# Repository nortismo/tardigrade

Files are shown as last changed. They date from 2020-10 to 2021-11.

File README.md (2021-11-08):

# Tardigrade

Tardigrade is an open hardware low-power board featuring NXP's LPC55S16 MCU, Semtech's SX1262 LoRa transceiver, u-blox's MAX-8Q GNSS module and Microchip's ATECC608A secure-element. It can be used as it is already or modified to your own needs. 

## Hardware

Schema and layout was created using [KiCad](https://kicad.org/).

## Software

There's a port of the official LoRaWAN stack implementation "LoRaMac-node" from Semtech for the Tardigrade board. The software is managed in a separate [GitHub repository](https://github.com/nortismo/LoRaMac-node).

## License

This hardware is licensed under the [TAPR Open Hardware License](https://tapr.org/the-tapr-open-hardware-license/). Please see the [LICENSE.txt](LICENSE.txt) file.

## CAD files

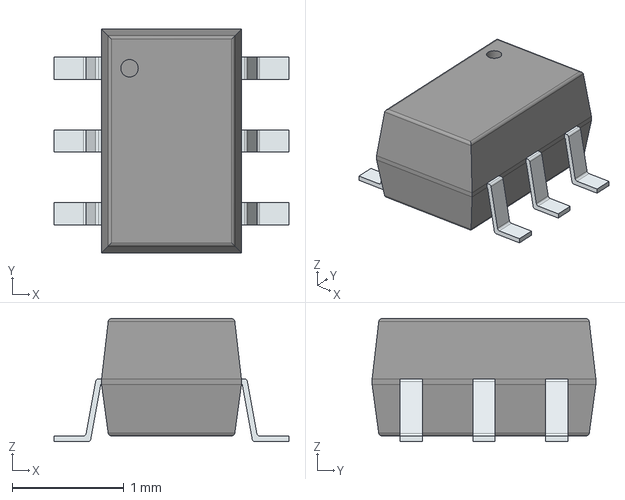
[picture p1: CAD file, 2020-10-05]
3d-models/MMDT2907A-7-F.stp
2.10 x 2.00 x 1.10 mm
PinsArrayLR

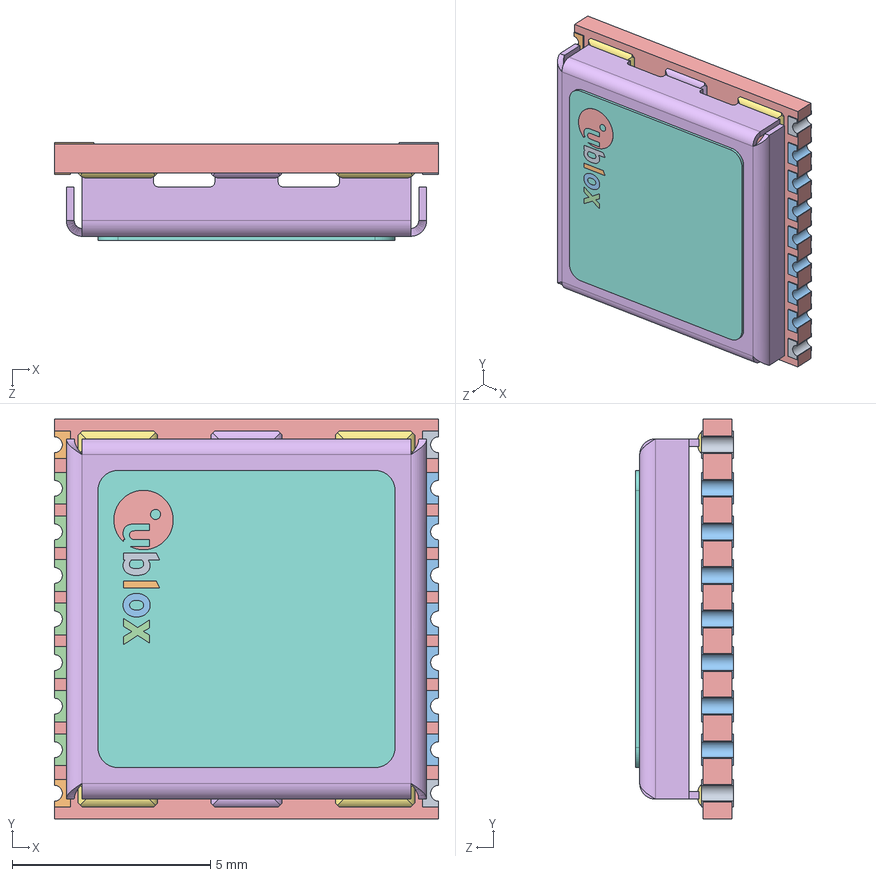
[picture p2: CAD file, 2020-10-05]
3d-models/MAX (STEP-AP203).STEP
9.70 x 10.1 x 2.47 mm
MAX_PCB
u-blox_MAX_label_Default
Shield

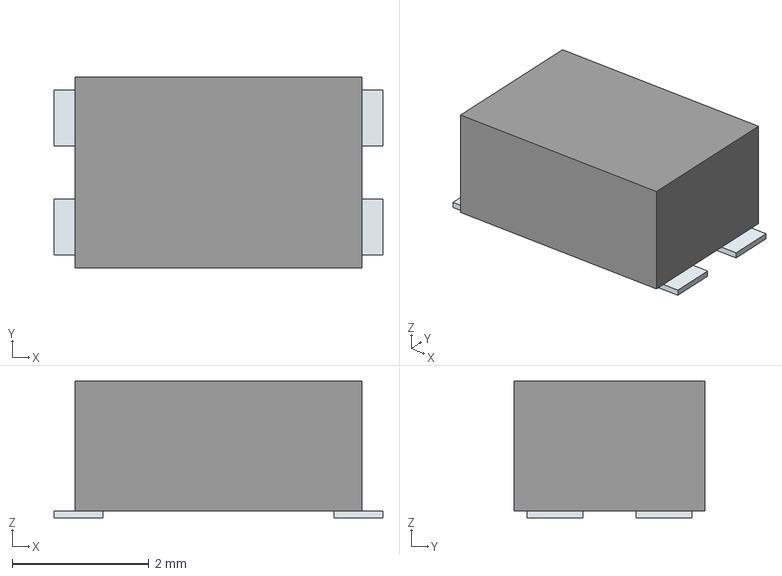
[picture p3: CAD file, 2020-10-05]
3d-models/KMR221NGLFS.stp
4.82 x 2.80 x 2.00 mm
Pins

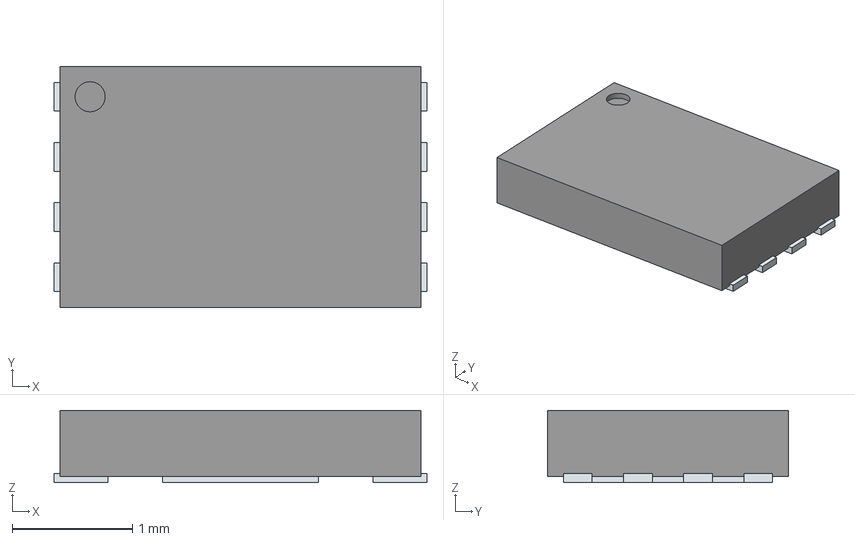
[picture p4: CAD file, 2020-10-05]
3d-models/ATECC608A-TNGLORAU-B.stp
3.10 x 2.00 x 0.6 mm
ThermalPin
PinsArrayLR

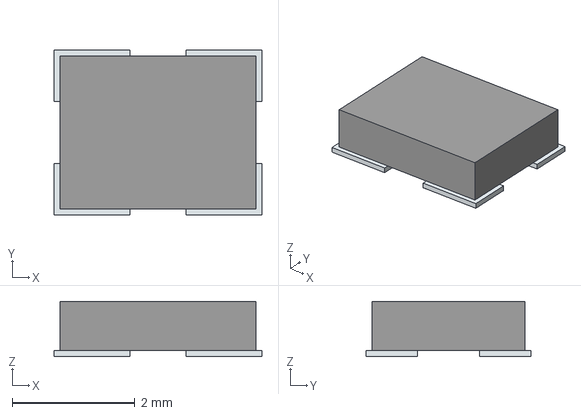
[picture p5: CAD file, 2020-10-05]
3d-models/CX3225SA40000D0PTWCC.stp
3.39 x 2.69 x 0.9 mm
Pins

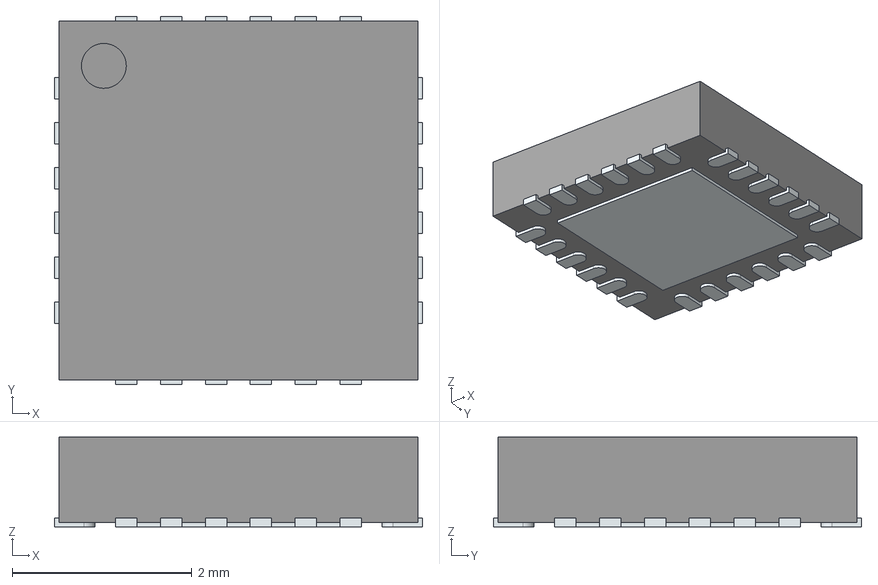
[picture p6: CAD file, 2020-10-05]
3d-models/SX1262IMLTRT.stp
4.10 x 4.10 x 1.00 mm
ThermalPin
PinsArrayLR
PinsArrayTB

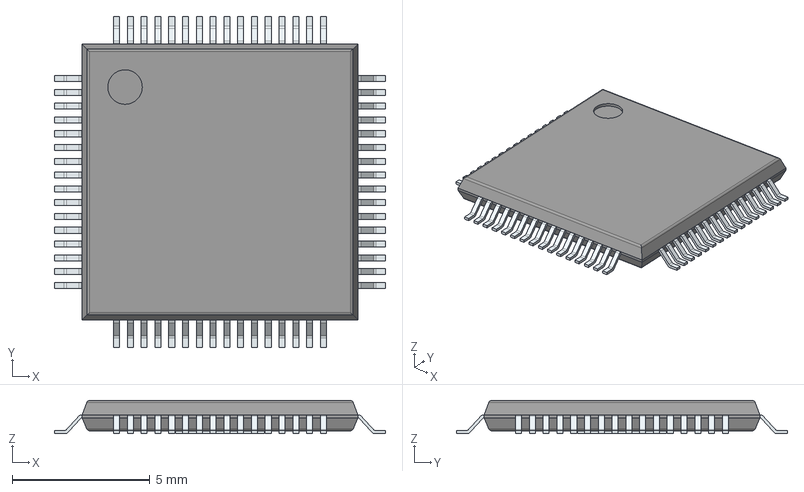
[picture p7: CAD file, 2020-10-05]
3d-models/LPC55S16JBD64E.stp
12.0 x 12.0 x 1.20 mm
PinsArrayLR
PinsArrayTB
ThermalPad

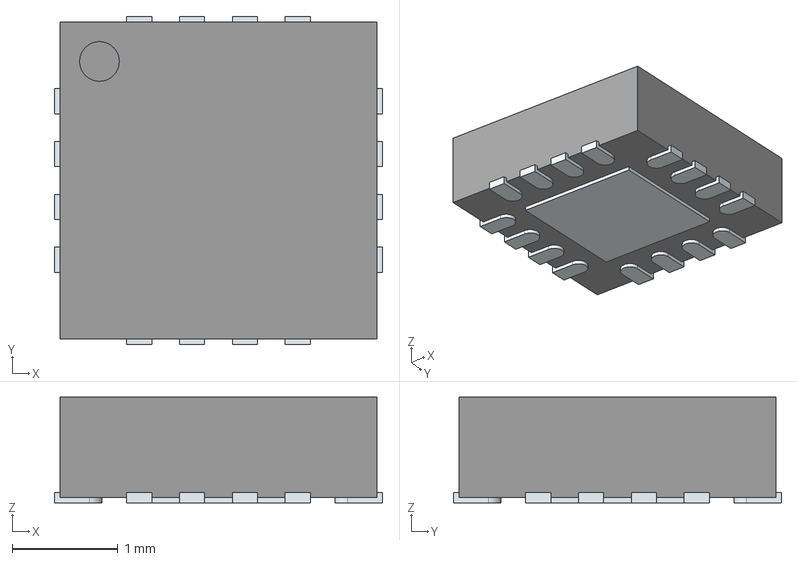
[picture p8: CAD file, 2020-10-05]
3d-models/BQ25504RGTT.stp
3.10 x 3.10 x 1.00 mm
ThermalPin
PinsArrayLR
PinsArrayTB

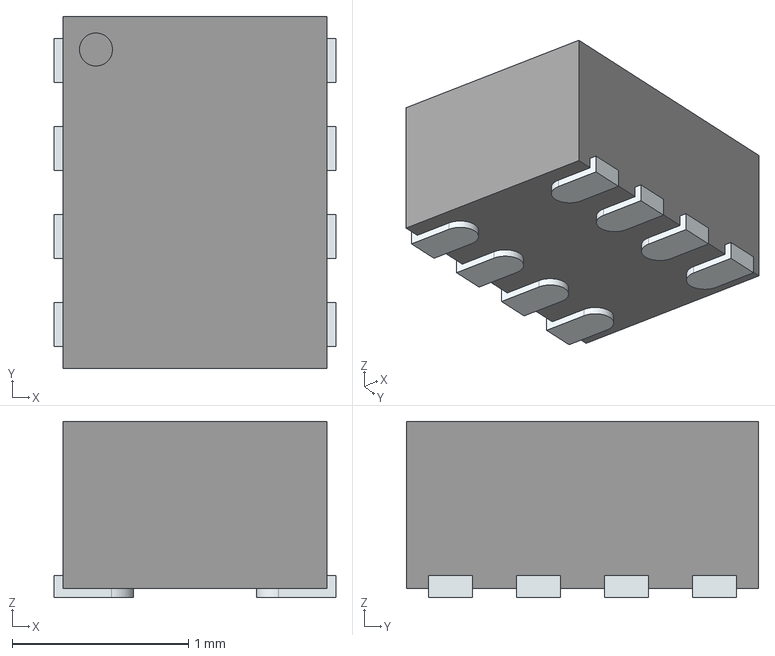
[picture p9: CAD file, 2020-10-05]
3d-models/TPS62840DLCR.stp
1.60 x 2.00 x 1.00 mm
PinsArrayLR

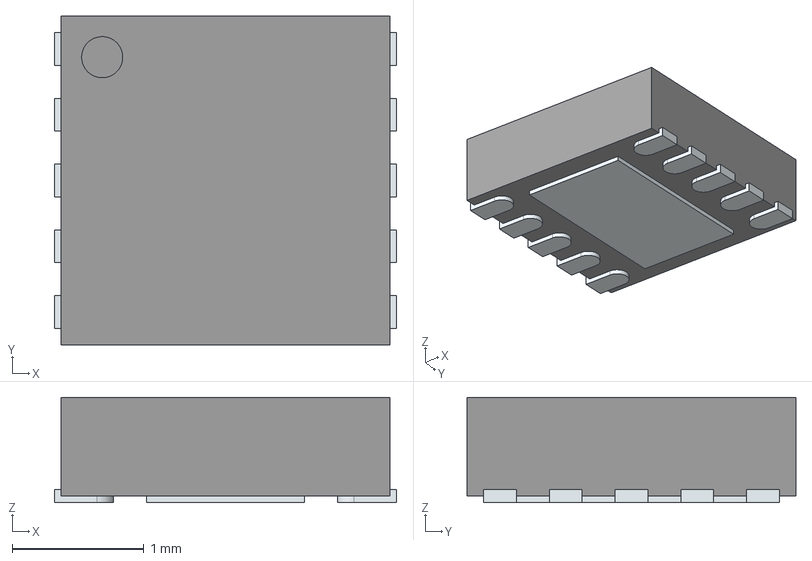
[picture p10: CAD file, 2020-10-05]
3d-models/TPS63031DSKR.stp
2.60 x 2.50 x 0.8 mm
ThermalPin
PinsArrayLR

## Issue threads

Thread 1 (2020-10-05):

L1 and L3 footprints are to small

nortismo, 2020-10-05:
# L1 and L3 footprints are too small

It's hard or nearly impossible to find a suitable L1 and L3 inductance with the desired values. Therefore different footprints for these two components have to be used, e.g. _0603 or_ even _0805_.

nortismo, 2020-11-12:
Footprints changed with commit fdd46cc9a01f37fd9c26f2f6ec00a6c7477109f7

Closed 2020-11-12.

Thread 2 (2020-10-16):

BQ_AVSS doesn't have a connection to GND

nortismo, 2020-10-16:
# BQ_AVSS doesn't have a connection to GND

The analog ground from BQ25504 called _BQ_AVSS_ doesn't have any connection to GND. Instead, it should be connected to GND as close as possible, directly at one point underneath the IC.

nortismo, 2020-11-05:
Fixed issue with commit d6d381544372e4fbed15211944ae5a9a2032be78 and added a connection between BQ_AVSS and GND

Closed 2020-11-05.

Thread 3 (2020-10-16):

BQ25504 doesn't start without solar power input

nortismo, 2020-10-16:
# BQ25504 doesn't start without solar power input

The IC BQ25504 doesn't start as long as there is no power from the solar panel, even if there is a voltage from VIN (battery or USB). Therefore the board only starts if one connects a solar panel or another power source to these pins.

nortismo, 2020-11-05:
Fixed issue with commit d6d381544372e4fbed15211944ae5a9a2032be78: Added a connection from VBUS to the solar panel with a resistor and a diode in between. This allows a small current flowing from VBUS to VIN_DC of the BQ25504 and therefore lets the boost converter start.

Closed 2020-11-05.

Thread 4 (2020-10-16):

Battery required to run the board on USB power

nortismo, 2020-10-16:
# Battery required to run the board on USB power

The Tardigrade can't be powered by USB without having a battery connected. The power ICs require a minimum capacitance which is given with the connected battery.

nortismo, 2020-11-05:
Fixed issue with commit d6d3815: Added a capacitor in front of the LIPO battery connector in order to be able to run the board without the battery.

Closed 2020-11-05.

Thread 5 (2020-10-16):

Missing C at LIPO charger MCP73831T

nortismo, 2020-10-16:
# Missing C at LIPO charger MCP73831T

The input pin VDD of the MCP73831T is missing a decoupling capacitor. To support the input power, a C of 10uF between VDD and GND can be placed as close as possible to the pin.

nortismo, 2020-11-05:
Fixed issue with commit d6d3815: Added the capacitor.

Closed 2020-11-05.

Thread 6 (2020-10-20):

C21 is wrong

nortismo, 2020-10-20:
# C21 is wrong

C21 should be a decoupling C for the input of _VDD_PMU_, but the schema is wrong. It must not be placed serially in line, but has to be connected parallel to Ground. Implementing it like designed in the schema, the MCU won't be powered correctly and the board doesn't work at all.

nortismo, 2020-11-05:
Fixed this issue with commit 966d3598cd48d5903a0eeb48dfa97b62b6b12088 - Schematic was changed accordingly with the proper placement of the capacitors.

Closed 2020-11-05.

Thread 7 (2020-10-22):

Connect RESET of SX1262 and GNSS to RESET button

nortismo, 2020-10-22:
# Connect RESET of SX1262 and GNSS to RESET button

In order to reset the whole board properly, the RESET line of the SX1262 and the GNSS module have to be connected to the RESET button as well. With the current schema, only the MCU is resetting when pressing that button. As a consequence, the initialization of the SX1262 doesn't work properly without a software reset first.

nortismo, 2020-11-05:
This won't be implemented and can be done with software.

Closed 2020-11-05.

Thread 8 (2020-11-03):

High power consumption of the LoRa transceiver resets the board

nortismo, 2020-11-03:
The LoRa transceiver SX1262 demands a lot of power over a short time when sending. This demand causes the voltage to collapse and resets the whole board.

nortismo, 2020-11-06:
This should be solved with commit 08f9730cbffbf505b7fb2e199a95f4603e357f8c: The DCDC converter is now directly connected to the battery and should deliver enough power for the lora transceiver.

Closed 2020-11-06.

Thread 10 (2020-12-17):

Add MOSFET to GNSS module in order to save power

nortismo, 2020-12-17:
Currently, the GNSS module MAX-8Q from u-blox can be put into backup mode to save power. But the module still consumes around 20 uA in this mode, which is quite a lot compared to the rest of the board. In order to bring down this value, one could add a P-Channel Enhancement MOSFET between VCC and the GNSS module. The power source to the GNSS module could then be turned on or off within the software running on the MCU.

One possible MOSFET is the [MIC94053YC6](http://ww1.microchip.com/downloads/en/DeviceDoc/mic94052-53.pdf) from Microchip. It even has an internal pull-up on the gateway pin in order to keep the pin high while there is nothing applied (which would happen when the LPC55S16 goes into deep power down mode). The MOSFET has a Zero Gate Voltage Drain Current of 1 uA. Therefore, we could save around 19 uA with this solution.

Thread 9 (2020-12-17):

SX1262_NSS pin requires pull-up resistor

nortismo, 2020-12-17:
The LPC55S16 leaves all pins floating when going to deep power down mode (lowest low power mode). In order to save power, one usually puts the peripherals like GNSS module or LoRa transceiver into sleep mode as well. But the LoRa transceiver wakes up automatically when the SPI slave select pin is going low. From the datasheet of the SX1261/2 LoRa transceiver:

> Once in SLEEP mode, it is possible to wake the device up from the host processor with a falling edge on the NSS line.

In order to keep the slave select high while the LPC55S16 is in deep power down, a pull-up resistor is required for pin 19 of the LoRa transceiver.

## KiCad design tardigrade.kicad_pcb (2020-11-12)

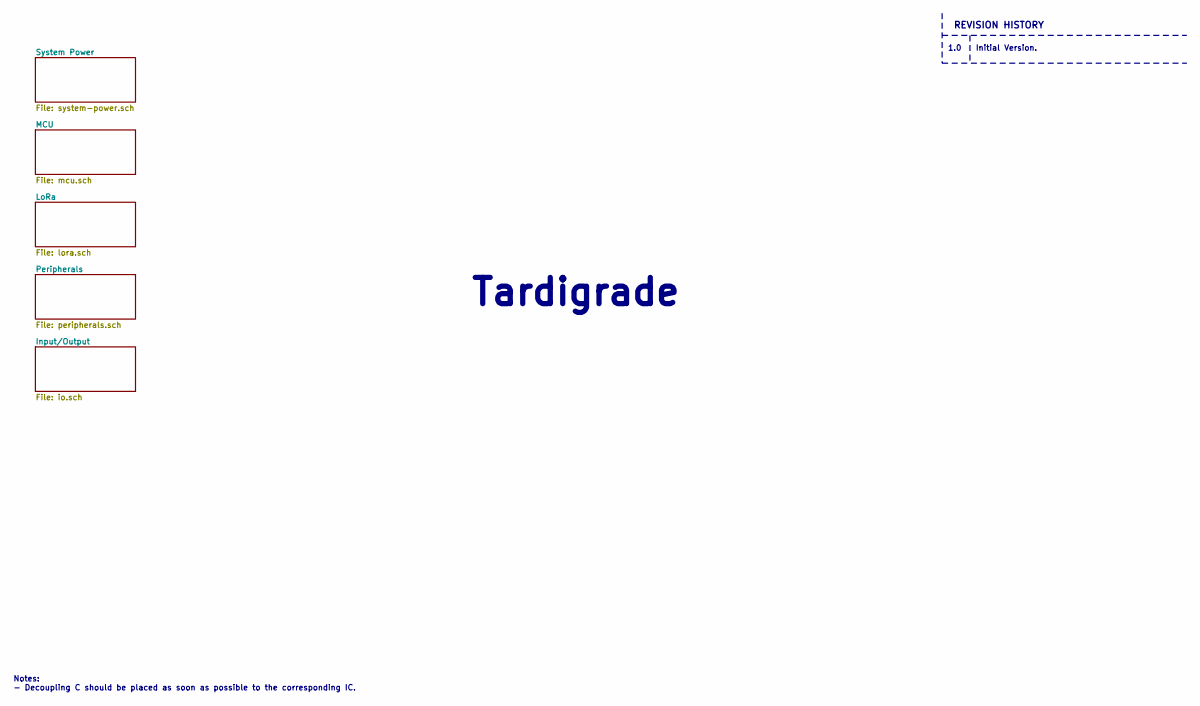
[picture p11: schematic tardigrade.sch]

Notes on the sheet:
REVISION HISTORY
1.0
Initial Version.
Tardigrade
Notes: - Decoupling C should be placed as soon as possible to the corresponding IC.

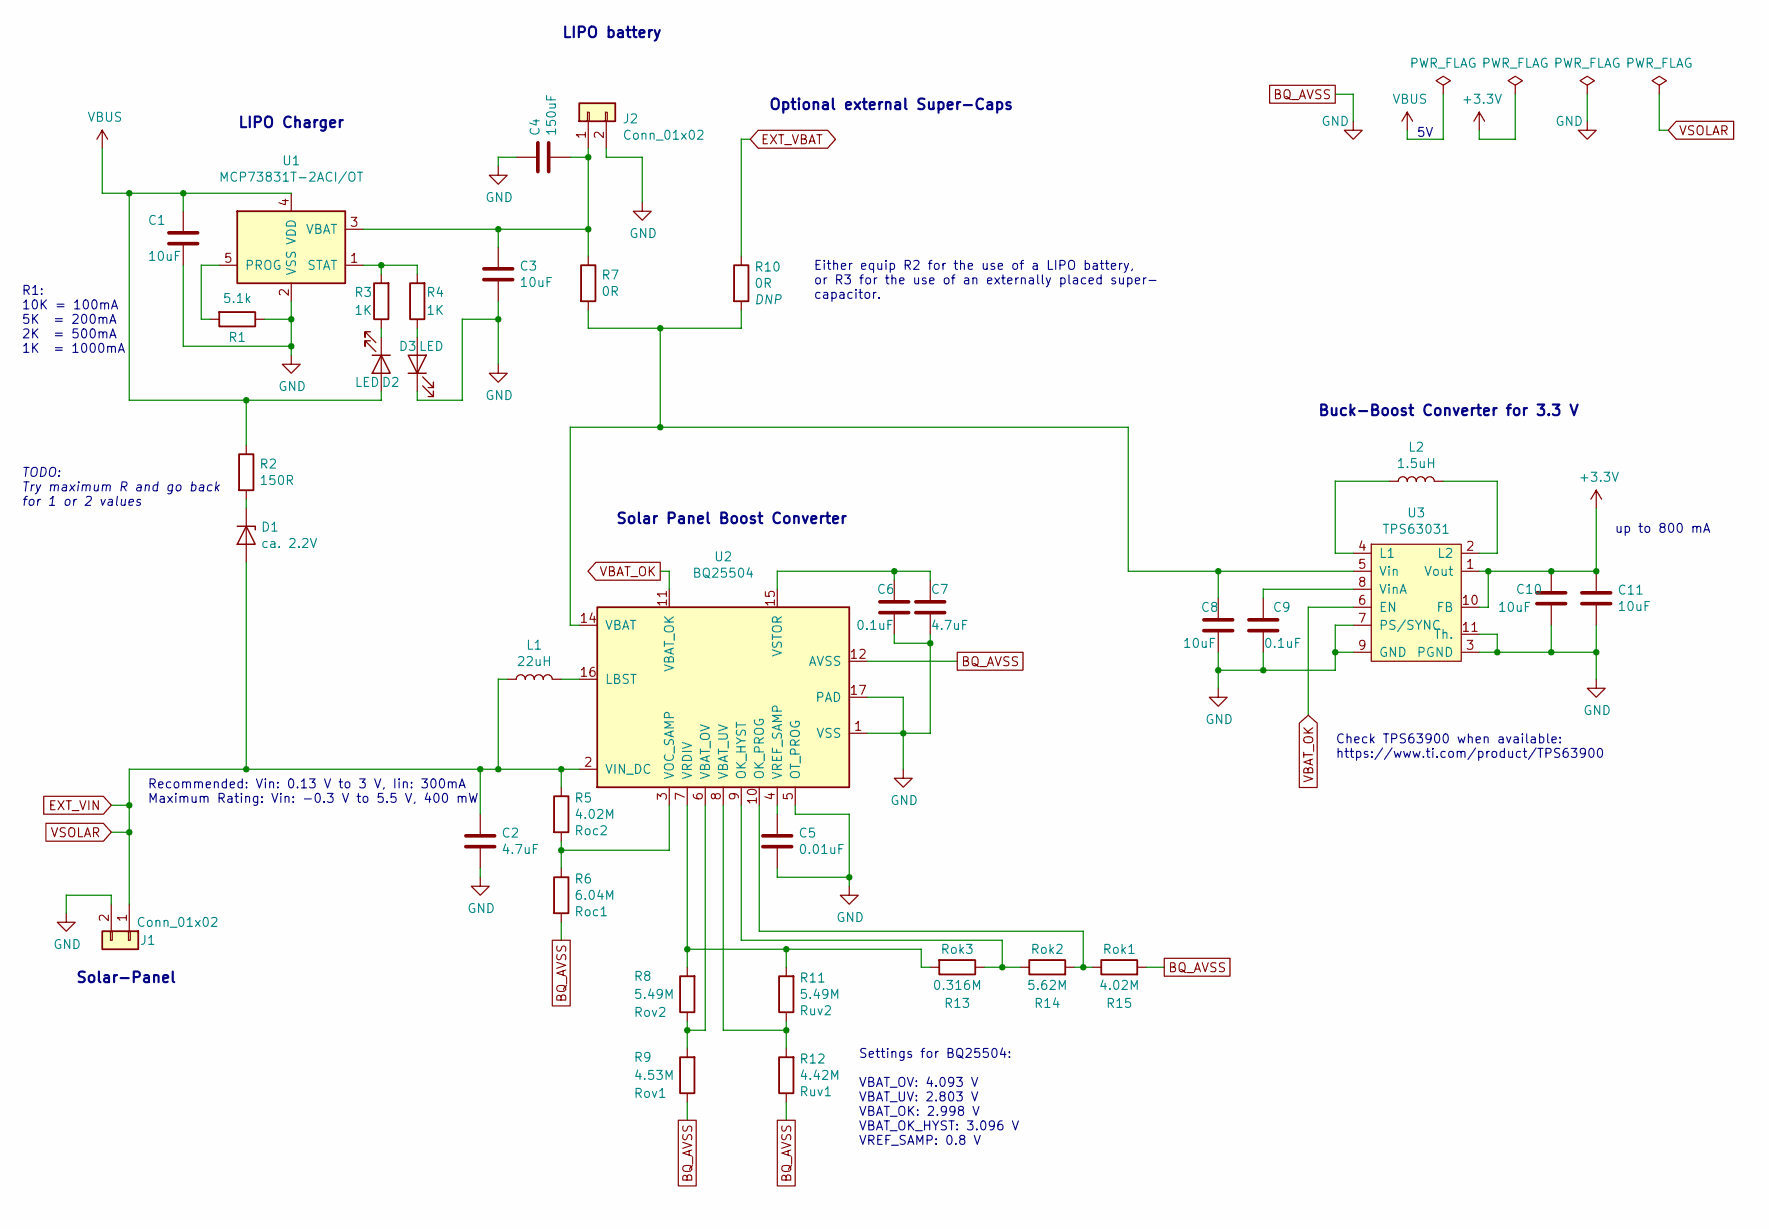
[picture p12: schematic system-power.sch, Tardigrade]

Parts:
C1, C3, C8, C10, C11: 10uF; C_0402_1005Metric
C2, C7: 4.7uF; C_0402_1005Metric
C4: 150uF; C_1206_3216Metric
C5: 0.01uF; C_0402_1005Metric
C6, C9: 0.1uF; C_0402_1005Metric
D1: ca. 2.2V; D_SOD-323
D2, D3: LED; LED_0603_1608Metric
J1, J2: Conn_01x02; JST_PH_S2B-PH-K_1x02_P2.00mm_Horizontal
L1: 22uH; L_0805_2012Metric
L2: 1.5uH; L_0402_1005Metric
R1: 5.1k; R_0402_1005Metric
R2: 150R; R_0402_1005Metric
R3, R4: 1K; R_0402_1005Metric
R5, R15: 4.02M; R_0402_1005Metric
R6: 6.04M; R_0402_1005Metric
R7, R10: 0R; R_0402_1005Metric
R8, R11: 5.49M; R_0402_1005Metric
R9: 4.53M; R_0402_1005Metric
R12: 4.42M; R_0402_1005Metric
R13: 0.316M; R_0402_1005Metric
R14: 5.62M; R_0402_1005Metric
U1: MCP73831T-2ACI/OT; SOT-23-5
U2: BQ25504; QFN50P300X300X100-17N-D
U3: TPS63031; TPS63031DSKR

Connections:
BQ_AVSS: C1.2, C2.2, C3.2, C4.1, C5.2, C6.2, C7.2, C8.2, C9.2, C10.2, C11.2, D3.1 (K), J1.2, J2.2, R1.1, R6.2, R9.1, R12.1, R15.2, U1.2 (VSS), U2.1 (VSS), U2.5 (OT_PROG), U2.12 (AVSS), U2.13 (VSS), U2.17 (PAD), U3.3 (PGND), U3.7 (PS/SYNC), U3.9 (GND), U3.11 (Th.); also elsewhere on the board
EXT_VBAT: R10.1; also elsewhere on the board
EXT_VIN: C2.1, D1.2 (A), J1.1, L1.1, R5.1, U2.2 (VIN_DC); also elsewhere on the board
unnamed: C3.1, C4.2, J2.1, R7.1, U1.3 (VBAT)
unnamed: C5.1, U2.4 (VREF_SAMP)
unnamed: C6.1, C7.1, U2.15 (VSTOR)
unnamed: C8.1, R7.2, R10.2, U2.14 (VBAT), U3.5 (Vin)
unnamed: C9.1, U3.8 (VinA)
unnamed: D1.1 (K), R2.2
unnamed: D2.1 (K), R3.1
unnamed: D3.2 (A), R4.1
unnamed: L1.2, U2.16 (LBST)
unnamed: L2.1, U3.4 (L1)
unnamed: L2.2, U3.2 (L2)
unnamed: R1.2, U1.5 (PROG)
unnamed: R3.2, R4.2, U1.1 (STAT)
unnamed: R5.2, R6.1, U2.3 (VOC_SAMP)
unnamed: R8.1, R9.2, U2.6 (VBAT_OV)
unnamed: R11.1, R12.2, U2.8 (VBAT_UV)
unnamed: R8.2, R11.2, R13.2, U2.7 (VRDIV)
unnamed: R13.1, R14.1, U2.9 (OK_HYST)
unnamed: R14.2, R15.1, U2.10 (OK_PROG)
VBAT_OK: U2.11 (VBAT_OK), U3.6 (EN); also elsewhere on the board
VBUS: C1.1, D2.2 (A), R2.1, U1.4 (VDD); also elsewhere on the board

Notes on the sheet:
R1: 10K = 100mA 5K = 200mA 2K = 500mA 1K = 1000mA
LIPO battery
Optional external Super-Caps
up to 800 mA
Recommended: Vin: 0.13 V to 3 V, Iin: 300mA Maximum Rating: Vin: -0.3 V to 5.5 V, 400 mW
Check TPS63900 when available: https://www.ti.com/product/TPS63900
LIPO Charger
Solar-Panel
Solar Panel Boost Converter
Buck-Boost Converter for 3.3 V
Settings for BQ25504: VBAT_OV: 4.093 V VBAT_UV: 2.803 V VBAT_OK: 2.998 V VBAT_OK_HYST: 3.096 V VREF_SAMP: 0.8 V
Either equip R2 for the use of a LIPO battery, or R3 for the use of an externally placed super- capacitor.
TODO: Try maximum R and go back for 1 or 2 values

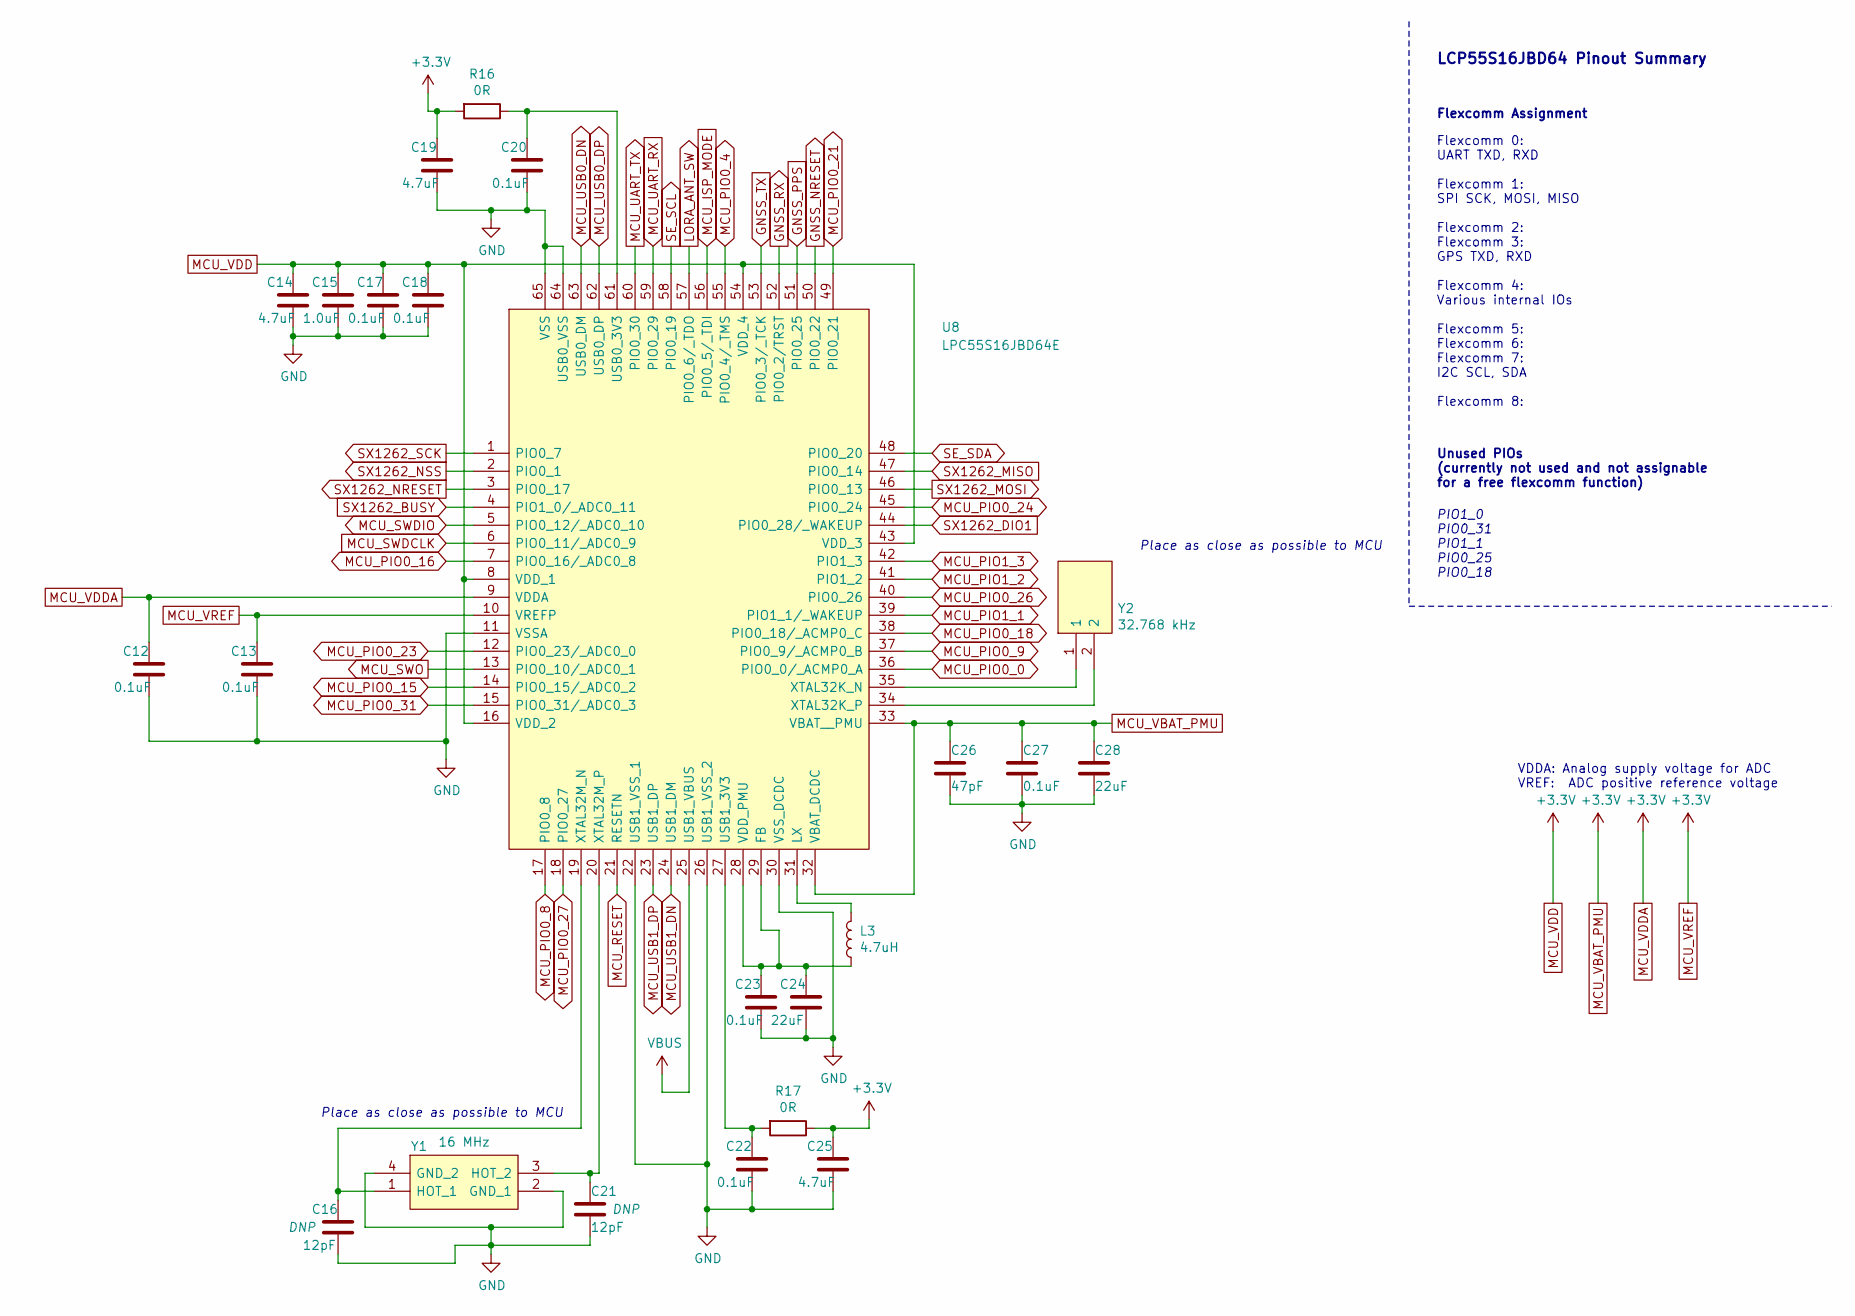
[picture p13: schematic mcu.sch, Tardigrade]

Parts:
C12, C13, C17, C18, C20, C22, C23, C27: 0.1uF; C_0402_1005Metric
C14, C19, C25: 4.7uF; C_0402_1005Metric
C15: 1.0uF; C_0402_1005Metric
C16, C21: 12pF; C_0402_1005Metric
C24, C28: 22uF; C_0603_1608Metric
C26: 47pF; C_0402_1005Metric
L3: 4.7uH; L_0805_2012Metric
R16, R17: 0R; R_0402_1005Metric
U8: LPC55S16JBD64E; QFP50P1200X1200X120-65N; Manufacturer_Part_Number LPC55S16JBD64E; Mouser Part Number 771-LPC55S16JBD64E
Y1: 16 MHz; CX3225SA16000
Y2: 32.768 kHz; FC-135_1; Manufacturer_Part_Number FC-135 32.7680KA-AG3; Mouser Part Number 732-FC135-32.76KAAG3

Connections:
BQ_AVSS: C12.2, C13.2, C14.2, C15.2, C16.2, C17.2, C18.2, C19.2, C20.2, C21.2, C22.2, C23.2, C24.2, C25.2, C26.2, C27.2, C28.2, U8.11 (VSSA), U8.22 (USB1_VSS_1), U8.26 (USB1_VSS_2), U8.30 (VSS_DCDC), U8.64 (USB0_VSS), U8.65 (VSS), Y1.2 (GND_1), Y1.4 (GND_2); also elsewhere on the board
GNSS_NRESET: U8.50 (PIO0_22); also elsewhere on the board
GNSS_PPS: U8.51 (PIO0_25); also elsewhere on the board
GNSS_RX: U8.52 (PIO0_2/TRST); also elsewhere on the board
GNSS_TX: U8.53 (PIO0_3/_TCK); also elsewhere on the board
LORA_ANT_SW: U8.57 (PIO0_6/_TDO); also elsewhere on the board
MCU_ISP_MODE: U8.56 (PIO0_5/_TDI); also elsewhere on the board
MCU_PIO0_0: U8.36 (PIO0_0/_ACMP0_A); also elsewhere on the board
MCU_PIO0_4: U8.55 (PIO0_4/_TMS); also elsewhere on the board
MCU_PIO0_8: U8.17 (PIO0_8); also elsewhere on the board
MCU_PIO0_9: U8.37 (PIO0_9/_ACMP0_B); also elsewhere on the board
MCU_PIO0_15: U8.14 (PIO0_15/_ADC0_2); also elsewhere on the board
MCU_PIO0_16: U8.7 (PIO0_16/_ADC0_8); also elsewhere on the board
MCU_PIO0_18: U8.38 (PIO0_18/_ACMP0_C); also elsewhere on the board
MCU_PIO0_21: U8.49 (PIO0_21); also elsewhere on the board
MCU_PIO0_23: U8.12 (PIO0_23/_ADC0_0); also elsewhere on the board
MCU_PIO0_24: U8.45 (PIO0_24); also elsewhere on the board
MCU_PIO0_26: U8.40 (PIO0_26); also elsewhere on the board
MCU_PIO0_27: U8.18 (PIO0_27); also elsewhere on the board
MCU_PIO0_31: U8.15 (PIO0_31/_ADC0_3); also elsewhere on the board
MCU_PIO1_1: U8.39 (PIO1_1/_WAKEUP); also elsewhere on the board
MCU_PIO1_2: U8.41 (PIO1_2); also elsewhere on the board
MCU_PIO1_3: U8.42 (PIO1_3); also elsewhere on the board
MCU_RESET: U8.21 (RESETN); also elsewhere on the board
MCU_SWDCLK: U8.6 (PIO0_11/_ADC0_9); also elsewhere on the board
MCU_SWDIO: U8.5 (PIO0_12/_ADC0_10); also elsewhere on the board
MCU_SWO: U8.13 (PIO0_10/_ADC0_1); also elsewhere on the board
MCU_UART_RX: U8.59 (PIO0_29); also elsewhere on the board
MCU_UART_TX: U8.60 (PIO0_30); also elsewhere on the board
MCU_USB0_DN: U8.63 (USB0_DM); also elsewhere on the board
MCU_USB0_DP: U8.62 (USB0_DP); also elsewhere on the board
MCU_USB1_DN: U8.24 (USB1_DM); also elsewhere on the board
MCU_USB1_DP: U8.23 (USB1_DP); also elsewhere on the board
unnamed: C16.1, U8.19 (XTAL32M_N), Y1.1 (HOT_1)
unnamed: C20.1, R16.1, U8.61 (USB0_3V3)
unnamed: C21.1, U8.20 (XTAL32M_P), Y1.3 (HOT_2)
unnamed: C22.1, R17.2, U8.27 (USB1_3V3)
unnamed: C23.1, C24.1, L3.1, U8.28 (VDD_PMU), U8.29 (FB)
unnamed: L3.2, U8.31 (LX)
unnamed: U8.34 (XTAL32K_P), Y2.2
unnamed: U8.35 (XTAL32K_N), Y2.1
SE_SCL: U8.58 (PIO0_19); also elsewhere on the board
SE_SDA: U8.48 (PIO0_20); also elsewhere on the board
SX1262_BUSY: U8.4 (PIO1_0/_ADC0_11); also elsewhere on the board
SX1262_DIO1: U8.44 (PIO0_28/_WAKEUP); also elsewhere on the board
SX1262_MISO: U8.47 (PIO0_14); also elsewhere on the board
SX1262_MOSI: U8.46 (PIO0_13); also elsewhere on the board
SX1262_NRESET: U8.3 (PIO0_17); also elsewhere on the board
SX1262_NSS: U8.2 (PIO0_1); also elsewhere on the board
SX1262_SCK: U8.1 (PIO0_7); also elsewhere on the board
VBUS: U8.25 (USB1_VBUS); also elsewhere on the board

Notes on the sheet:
Flexcomm 0: UART TXD, RXD Flexcomm 1: SPI SCK, MOSI, MISO Flexcomm 2: Flexcomm 3: GPS TXD, RXD Flexcomm 4: Various internal IOs Flexcomm 5: Flexcomm 6: Flexcomm 7: I2C SCL, SDA Flexcomm 8:
PIO1_0 PIO0_31 PIO1_1 PIO0_25 PIO0_18
LCP55S16JBD64 Pinout Summary
Flexcomm Assignment
Unused PIOs (currently not used and not assignable for a free flexcomm function)
Place as close as possible to MCU
VDDA: Analog supply voltage for ADC VREF: ADC positive reference voltage

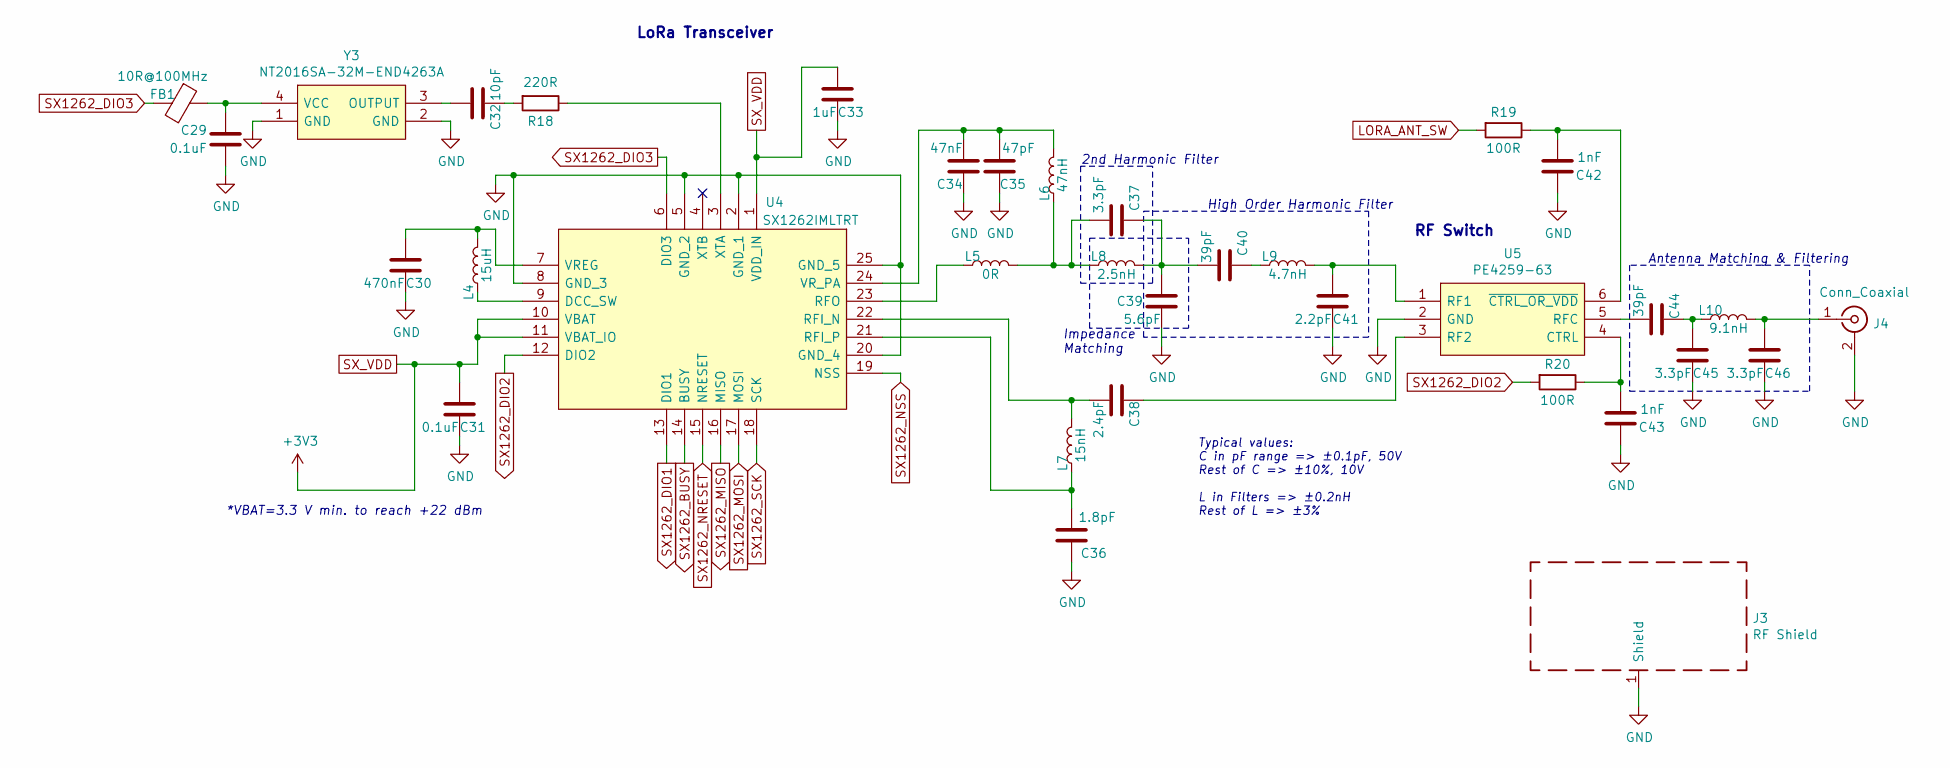
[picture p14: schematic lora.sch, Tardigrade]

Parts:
C29, C31: 0.1uF; C_0402_1005Metric
C30: 470nF; C_0402_1005Metric
C32: 10pF; C_0402_1005Metric
C33: 1uF; C_0402_1005Metric
C34: 47nF; C_0402_1005Metric
C35: 47pF; C_0402_1005Metric
C36: 1.8pF; C_0402_1005Metric
C37, C45, C46: 3.3pF; C_0402_1005Metric
C38: 2.4pF; C_0402_1005Metric
C39: 5.6pF; C_0402_1005Metric
C40, C44: 39pF; C_0402_1005Metric
C41: 2.2pF; C_0402_1005Metric
C42, C43: 1nF; C_0402_1005Metric
FB1: 10R@100MHz; C_0402_1005Metric
J3: RF Shield; Laird_Technologies_BMI-S-209-F_29.36x18.50mm
J4: Conn_Coaxial; U.FL_Hirose_U.FL-R-SMT-1_Vertical
L4: 15uH; L_0805_2012Metric
L5: 0R; L_0402_1005Metric
L6: 47nH; L_0402_1005Metric
L7: 15nH; L_0402_1005Metric
L8: 2.5nH; L_0402_1005Metric
L9: 4.7nH; L_0402_1005Metric
L10: 9.1nH; L_0402_1005Metric
R18: 220R; R_0402_1005Metric
R19, R20: 100R; R_0402_1005Metric
U4: SX1262IMLTRT; QFN50P400X400X100-25N-D; Manufacturer_Part_Number SX1262IMLTRT; Mouser Part Number 947-SX1262IMLTRT
U5: PE4259-63; SOT65P210X110-6N; Manufacturer_Part_Number PE4259-63
Y3: NT2016SA-32M-END4263A; NT2016SA; Manufacturer_Part_Number NT2016SA-32M-END4263A

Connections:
BQ_AVSS: C29.1, C30.1, C31.1, C33.1, C34.1, C35.1, C36.1, C39.1, C41.1, C42.1, C43.1, C45.1, C46.1, J3.1, J4.2 (Ext), U4.2 (GND_1), U4.5 (GND_2), U4.8 (GND_3), U4.20 (GND_4), U4.25 (GND_5), U5.2 (GND), Y3.1 (GND), Y3.2 (GND); also elsewhere on the board
LORA_ANT_SW: R19.2; also elsewhere on the board
unnamed: C29.2, FB1.1, Y3.4 (VCC)
unnamed: C30.2, L4.2, U4.7 (VREG)
unnamed: C32.1, R18.2
unnamed: C32.2, Y3.3 (OUTPUT)
unnamed: C34.2, C35.2, L6.2, U4.24 (VR_PA)
unnamed: C36.2, L7.1, U4.21 (RFI_P)
unnamed: C37.1, C39.2, C40.2, L8.2
unnamed: C37.2, L5.2, L6.1, L8.1
unnamed: C38.1, U5.3 (RF2)
unnamed: C38.2, L7.2, U4.22 (RFI_N)
unnamed: C40.1, L9.1
unnamed: C41.2, L9.2, U5.1 (RF1)
unnamed: C42.2, R19.1, U5.6 (~CTRL_OR_VDD)
unnamed: C43.2, R20.1, U5.4 (CTRL)
unnamed: C44.1, C45.2, L10.1
unnamed: C44.2, U5.5 (RFC)
unnamed: C46.2, J4.1 (In), L10.2
unnamed: L4.1, U4.9 (DCC_SW)
unnamed: L5.1, U4.23 (RFO)
unnamed: R18.1, U4.3 (XTA)
SX1262_BUSY: U4.14 (BUSY); also elsewhere on the board
SX1262_DIO1: U4.13 (DIO1); also elsewhere on the board
SX1262_DIO2: R20.2, U4.12 (DIO2)
SX1262_DIO3: FB1.2, U4.6 (DIO3)
SX1262_MISO: U4.16 (MISO); also elsewhere on the board
SX1262_MOSI: U4.17 (MOSI); also elsewhere on the board
SX1262_NRESET: U4.15 (NRESET); also elsewhere on the board
SX1262_NSS: U4.19 (NSS); also elsewhere on the board
SX1262_SCK: U4.18 (SCK); also elsewhere on the board

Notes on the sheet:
RF Switch
*VBAT=3.3 V min. to reach +22 dBm
LoRa Transceiver
2nd Harmonic Filter
Impedance Matching
High Order Harmonic Filter
Antenna Matching & Filtering
Typical values: C in pF range => ±0.1pF, 50V Rest of C => ±10%, 10V L in Filters => ±0.2nH Rest of L => ±3%

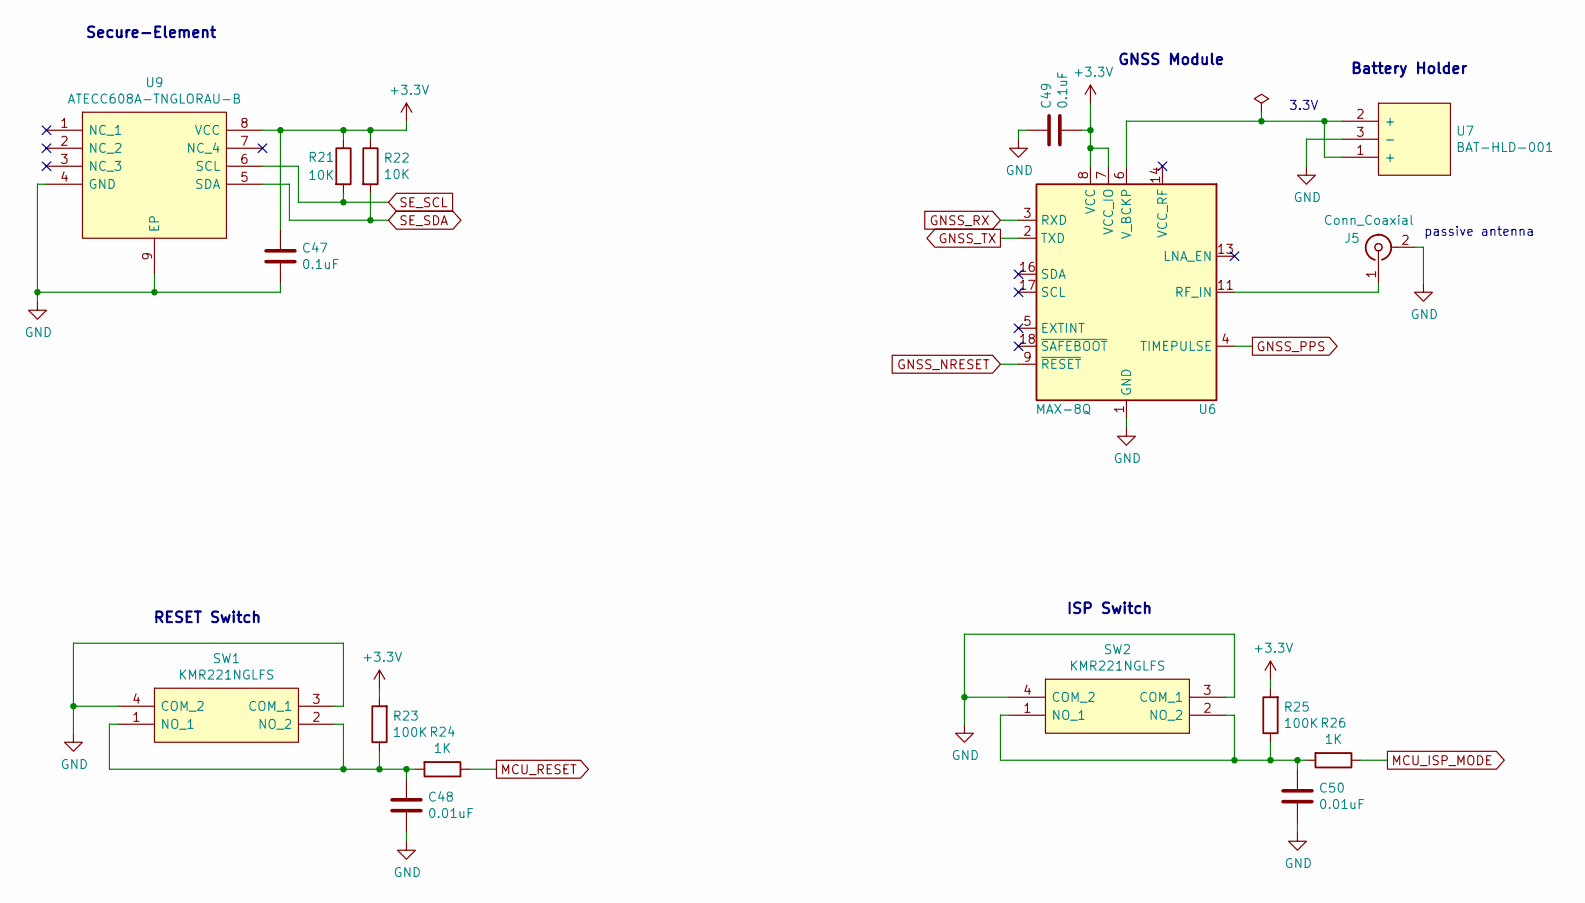
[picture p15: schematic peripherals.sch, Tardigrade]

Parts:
C47, C49: 0.1uF; C_0402_1005Metric
C48, C50: 0.01uF; C_0402_1005Metric
J5: Conn_Coaxial; U.FL_Hirose_U.FL-R-SMT-1_Vertical
R21, R22: 10K; R_0402_1005Metric
R23, R25: 100K; R_0402_1005Metric
R24, R26: 1K; R_0402_1005Metric
SW1, SW2: KMR221NGLFS; Manufacturer_Part_Number KMR221NGLFS; Mouser Part Number 611-KMR221NGLFS
U6: MAX-8Q; ublox_MAX
U7: BAT-HLD-001; BATHLD001; Manufacturer_Part_Number BAT-HLD-001; Mouser Part Number 712-BAT-HLD-001
U9: ATECC608A-TNGLORAU-B; SON50P300X200X60-9N; Manufacturer_Part_Number ATECC608A-TNGLORAU-B

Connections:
BQ_AVSS: C47.2, C48.2, C49.1, C50.2, J5.2 (Ext), SW1.3 (COM_1), SW1.4 (COM_2), SW2.3 (COM_1), SW2.4 (COM_2), U6.1 (GND), U6.10 (GND), U6.12 (GND), U7.3 (-), U9.4 (GND), U9.9 (EP); also elsewhere on the board
GNSS_NRESET: U6.9 (~RESET); also elsewhere on the board
GNSS_PPS: U6.4 (TIMEPULSE); also elsewhere on the board
GNSS_RX: U6.3 (RXD); also elsewhere on the board
GNSS_TX: U6.2 (TXD); also elsewhere on the board
MCU_ISP_MODE: R26.1; also elsewhere on the board
MCU_RESET: R24.1; also elsewhere on the board
unnamed: C48.1, R23.1, R24.2, SW1.1 (NO_1), SW1.2 (NO_2)
unnamed: C50.1, R25.1, R26.2, SW2.1 (NO_1), SW2.2 (NO_2)
unnamed: J5.1 (In), U6.11 (RF_IN)
unnamed: U6.6 (V_BCKP), U7.1 (+), U7.2 (+)
SE_SCL: R21.2, U9.6 (SCL); also elsewhere on the board
SE_SDA: R22.2, U9.5 (SDA); also elsewhere on the board

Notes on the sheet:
Secure-Element
GNSS Module
RESET Switch
ISP Switch
Battery Holder
3.3V
passive antenna

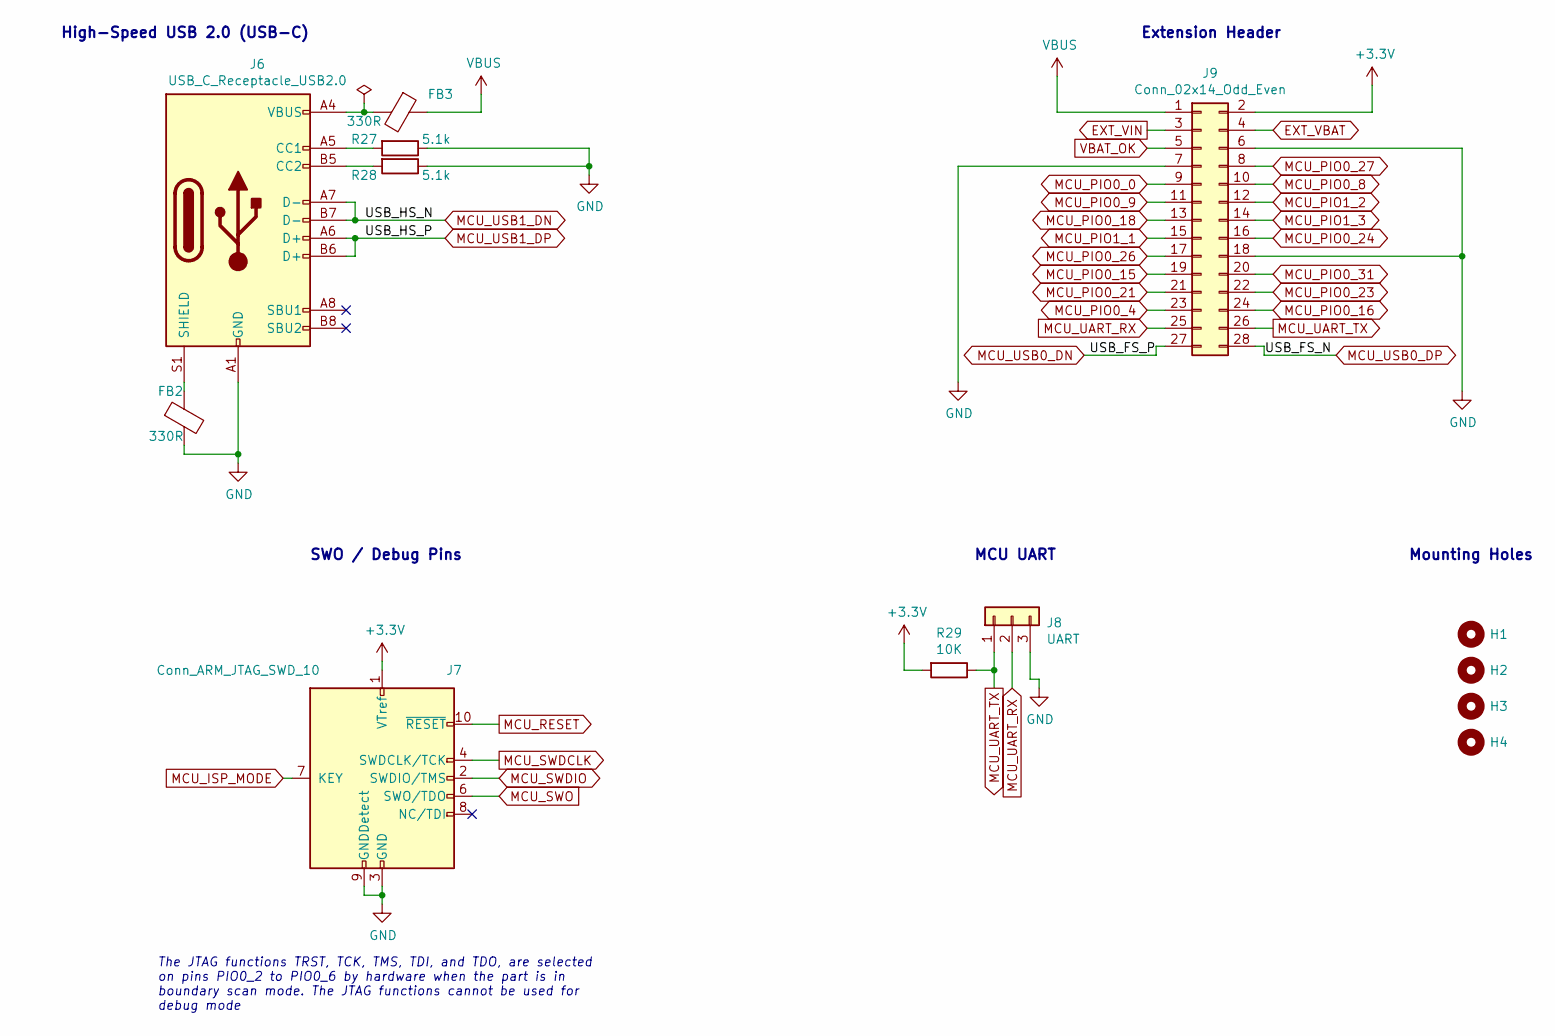
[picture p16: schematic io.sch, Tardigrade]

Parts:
FB2, FB3: 330R; C_0402_1005Metric
H1, H2, H3, H4: MountingHole; MountingHole_2.2mm_M2_Pad
J6: USB_C_Receptacle_USB2.0; USB_C_Receptacle_JAE_DX07S016JA1
J7: Conn_ARM_JTAG_SWD_10; PinHeader_2x05_P1.27mm_Vertical
J8: UART; PinHeader_1x03_P2.54mm_Vertical
J9: Conn_02x14_Odd_Even; PinHeader_2x14_P2.54mm_Vertical
R27, R28: 5.1k; R_0402_1005Metric
R29: 10K; R_0402_1005Metric

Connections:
BQ_AVSS: FB2.2, J6.A1 (GND), J6.A12 (GND), J6.B1 (GND), J6.B12 (GND), J7.3 (GND), J7.5 (GND), J7.9 (GNDDetect), J8.3, J9.6, J9.7, J9.18, R27.1, R28.1; also elsewhere on the board
EXT_VBAT: J9.4; also elsewhere on the board
EXT_VIN: J9.3; also elsewhere on the board
MCU_ISP_MODE: J7.7 (KEY); also elsewhere on the board
MCU_PIO0_0: J9.9; also elsewhere on the board
MCU_PIO0_4: J9.23; also elsewhere on the board
MCU_PIO0_8: J9.10; also elsewhere on the board
MCU_PIO0_9: J9.11; also elsewhere on the board
MCU_PIO0_15: J9.19; also elsewhere on the board
MCU_PIO0_16: J9.24; also elsewhere on the board
MCU_PIO0_18: J9.13; also elsewhere on the board
MCU_PIO0_21: J9.21; also elsewhere on the board
MCU_PIO0_23: J9.22; also elsewhere on the board
MCU_PIO0_24: J9.16; also elsewhere on the board
MCU_PIO0_26: J9.17; also elsewhere on the board
MCU_PIO0_27: J9.8; also elsewhere on the board
MCU_PIO0_31: J9.20; also elsewhere on the board
MCU_PIO1_1: J9.15; also elsewhere on the board
MCU_PIO1_2: J9.12; also elsewhere on the board
MCU_PIO1_3: J9.14; also elsewhere on the board
MCU_RESET: J7.10 (~RESET~); also elsewhere on the board
MCU_SWDCLK: J7.4 (SWDCLK/TCK); also elsewhere on the board
MCU_SWDIO: J7.2 (SWDIO/TMS); also elsewhere on the board
MCU_SWO: J7.6 (SWO/TDO); also elsewhere on the board
MCU_UART_RX: J8.2, J9.25; also elsewhere on the board
MCU_UART_TX: J8.1, J9.26, R29.1; also elsewhere on the board
MCU_USB0_DN: J9.27; also elsewhere on the board
MCU_USB0_DP: J9.28; also elsewhere on the board
MCU_USB1_DN: J6.A7 (D-), J6.B7 (D-); also elsewhere on the board
MCU_USB1_DP: J6.A6 (D+), J6.B6 (D+); also elsewhere on the board
unnamed: FB2.1, J6.S1 (SHIELD)
unnamed: FB3.2, J6.A4 (VBUS), J6.A9 (VBUS), J6.B4 (VBUS), J6.B9 (VBUS)
unnamed: J6.A5 (CC1), R27.2
unnamed: J6.B5 (CC2), R28.2
VBAT_OK: J9.5; also elsewhere on the board
VBUS: FB3.1, J9.1; also elsewhere on the board

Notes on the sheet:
The JTAG functions TRST, TCK, TMS, TDI, and TDO, are selected on pins PIO0_2 to PIO0_6 by hardware when the part is in boundary scan mode. The JTAG functions cannot be used for debug mode
SWO / Debug Pins
High-Speed USB 2.0 (USB-C)
MCU UART
Extension Header
Mounting Holes

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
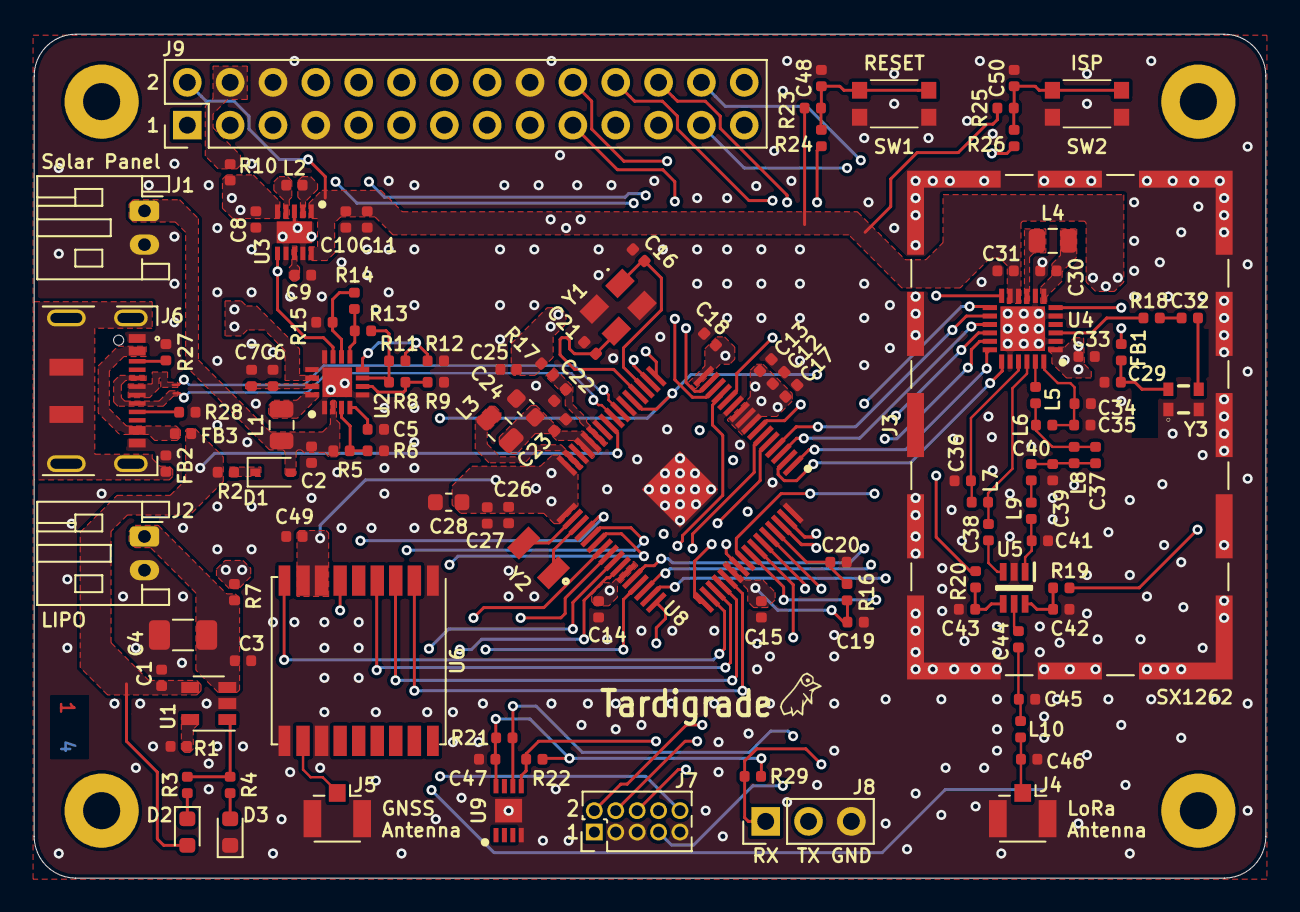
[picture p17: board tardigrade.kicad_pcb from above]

Board: 4 copper layers, 73.0 x 50.0 mm, 122 parts (1 on the bottom side), 104 nets.

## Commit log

2020-10-30 Added notes for new design
    [system-power.sch]
2020-11-05 Fixed issue #2, #3, #4 and #5
    [io.sch, lora.sch, mcu.sch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]
2020-11-05 Issue #6 - Fixed wrong placement of C21
    [mcu.sch]
2020-11-05 Removed unnecessary leds from system-power to save power
    [system-power.sch]
2020-11-05 Removed jumpers from system-power
    [system-power.sch]
2020-11-05 Removed BAT_OK signal from MCU
    [mcu.sch]
2020-11-05 Removed jumpers from mcu
    [mcu.sch]
2020-11-05 Removed jumpers from peripherals
    [peripherals.sch]
2020-11-05 Removed jumpers from ios
    [io.sch, mcu.sch, peripherals.sch]
2020-11-05 Changed extension header symbol
    [io.sch]
2020-11-05 Changed all symbols names from IC to U
    [io.sch, lora.sch, mcu.sch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]
2020-11-05 Unnecessary note removed
    [lora.sch, mcu.sch, peripherals.sch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]
2020-11-05 Changed pin assignment on mcu and extension header
    [io.sch, mcu.sch, peripherals.sch]
2020-11-05 Changed order of input capacitance to bq
    [system-power.sch]
2020-11-05 Added footprint assignment
    [io.sch, lora.sch, mcu.sch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]
2020-11-06 Review done
    [io.sch, lora.sch, mcu.sch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]
2020-11-12 Major change of the layout (reviewed) for V1.1
    [io.sch, lora.sch, mcu.sch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]
2020-11-12 Updated headers/footers of files
    [io.sch, lora.sch, mcu.sch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]
2020-12-17 Changed notes on system power schematic
    [system-power.sch]
2020-12-18 Added revision comment on schema
    [tardigrade.sch]
2021-11-08 Update README.md
    https://forum.kicad.info/t/warning-avoid-all-links-to-kicad-pcb-org-use-kicad-org/31521
